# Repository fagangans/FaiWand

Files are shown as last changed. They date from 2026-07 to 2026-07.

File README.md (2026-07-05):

# AI Magic Wand (ESP32 + MPU6050 + OLED + Mic + Speaker)

Proyek "AI Magic Wand" terinspirasi dari [TensorFlow Lite Magic Wand Codelab](https://codelabs.developers.google.com/codelabs/ai-magicwand)
Google, tapi dibangun dengan hardware yang jauh lebih murah dan gampang didapat:
**ESP32 DevKit V1 + MPU6050 + OLED SSD1306 0.96" + mikrofon I2S (INMP441) + speaker
I2S (MAX98357A)**, terintegrasi dengan **AI lokal (speech-to-speech dua arah)** milik
kamu sendiri di jaringan LAN — bukan cloud API.

Kamu bisa **bicara ke tongkat** (push-to-talk, tahan tombol BOOT) dan AI menjawab lewat
suara + teks di tongkat, ATAU **menggerakkan tongkat** (gesture) untuk trigger respons
tetap yang lebih ringkas.

## Struktur repo

```
firmware/magic_wand/     -> Sketch Arduino (buka magic_wand.ino di Arduino IDE)
server/                   -> Server AI lokal Node.js (gesture/suara -> teks + audio TTS)
docs/BOM.md               -> Daftar komponen + estimasi harga
docs/WIRING.md             -> Panduan wiring lengkap + setup jaringan AI lokal
docs/EDGE_IMPULSE_GUIDE.md -> Cara training model gesture custom
docs/ENCLOSURE.md          -> Saran casing/enclosure tongkat
enclosure/                 -> Model 3D gagang (.scad + .stl siap print)
```

## Arsitektur singkat

```
                     ┌── GESTURE (Lumos/Wave/Circle) ──┐   ┌── PUSH-TO-TALK (tombol BOOT) ──┐
                     |  MPU6050 -> ESP32 klasifikasi    |   |  Mikrofon I2S rekam ke RAM      |
                     v                                  v   v
                              WiFi (LAN) --> Server AI lokal kamu
                                        |
                    (gesture: prompt tetap per gesture)
                    (suara: transkrip Whisper lokal -> jadi prompt)
                                        |
                         ┌──────────────┴──────────────┐
                         v                              v
                  Teks respons AI                Audio TTS (mp3)
                  (JSON, untuk OLED)         (di-stream via HTTP ke ESP32)
                         |                              |
                         v                              v
                  Tampil di OLED          Dimainkan lewat speaker I2S
                                          di tongkat (MAX98357A + speaker)
```

**Kenapa klasifikasi gesture tetap on-device (bukan kirim raw sensor ke AI)?** Time-series
classification real-time tidak cocok dikirim sebagai data mentah — lambat dan boros
baterai/bandwidth. Jadi gesture diklasifikasi lokal di ESP32 (model kecil via Edge Impulse,
atau fallback threshold sederhana), baru **hasil klasifikasinya** yang dikirim ke server.

**Kenapa suara (TTS & STT) diproses di server tapi didengar/direkam di tongkat?** ESP32
tidak mampu generate suara atau transkrip suara sendiri — terlalu berat untuk board sekecil
ini. Server (komputer kamu) yang punya daya proses untuk itu:
- **Bicara ke tongkat**: ESP32 rekam suara ke RAM → kirim WAV ke server → server transkrip
  (Whisper lokal, offline) → AI jawab sesuai isi omongan → jawaban (teks+audio) dikirim balik.
- **Tongkat menjawab**: server generate teks + audio TTS → ESP32 **streaming** audio itu dan
  memutarnya langsung lewat speaker I2S di tongkat.

Hasilnya speech-to-speech terasa benar-benar terjadi di tongkat, walau otak pemrosesannya
ada di server lokal kamu.

## Quick start

1. **Hardware**: ikuti `docs/BOM.md` dan `docs/WIRING.md` untuk rakit board (OLED, speaker
   I2S, DAN mikrofon I2S).
2. **Software firmware**:
   - Install Arduino IDE + board support "esp32" (via Boards Manager, cari "esp32" by Espressif).
   - Install library lewat Library Manager: `Adafruit MPU6050`, `Adafruit Unified Sensor`,
     `Adafruit SSD1306`, `Adafruit GFX Library`, `ArduinoJson`, `ESP32-audioI2S` (by schreibfaul1).
     (Mikrofon pakai driver I2S bawaan Arduino-ESP32 core, tidak perlu library tambahan.)
   - Buka folder `firmware/magic_wand/` di Arduino IDE (buka file `magic_wand.ino`).
   - Copy `secrets.h.example` jadi `secrets.h`, isi WiFi SSID/password dan `LOCAL_AI_HOST`
     (hostname mDNS atau IP server AI lokal kamu).
   - Pilih board **"ESP32 Dev Module"** di Tools > Board, pilih port yang sesuai, lalu Upload.
3. **Server AI lokal**: implementasi siap pakai ada di `server/` (Node.js, tanpa API key untuk
   chat AI — pakai AI4Chat + TTS Edge Neural Voice + STT Whisper lokal). Jalankan:
   ```
   cd server && npm install && npm start
   ```
   Lihat `server/README.md` untuk detail kontrak API (`/gesture`, `/voice`, `/audio/:file`).
4. **Test awal (tanpa training model dulu)**: firmware default pakai fallback threshold
   sederhana untuk gesture (`USE_EDGE_IMPULSE_MODEL 0` di `gesture_classifier.h`) — cukup
   untuk memverifikasi wiring, LED, OLED, speaker, mikrofon, dan koneksi ke server AI lokal
   sebelum kamu invest waktu training model gesture asli.
5. **Training model gesture asli**: ikuti `docs/EDGE_IMPULSE_GUIDE.md` step-by-step.
6. **Casing**: file 3D print siap pakai ada di `enclosure/` (STL + sumber `.scad`, sudah
   termasuk lubang mikrofon), atau lihat opsi lain di `docs/ENCLOSURE.md`.

## Cara pakai

| Metode | Aksi |
|---|---|
| **Push-to-talk** | Tahan tombol BOOT, bicara, lepas untuk kirim. AI jawab SESUAI ISI OMONGAN kamu. |
| Gesture `Lumos` | LED menyala kuning terang, tahan ~1.2 detik; nama gesture tampil di OLED |
| Gesture `Wave` | LED kedip biru 4x, kirim ke server AI (prompt TETAP "sapa pengguna..."), tampil + suarakan respons |
| Gesture `Circle` | LED efek sweep ungu-pink; nama gesture tampil di OLED |

Gesture, warna, prompt tetap tiap gesture, dan mana yang trigger AI semuanya bisa diubah di
`firmware/magic_wand/led_effects.cpp`, `firmware/magic_wand/magic_wand.ino`, dan
`server/gesture_server.js` (`GESTURE_PROMPTS`).

## Power management

- Board masuk **deep sleep** otomatis setelah idle (default 30 detik, ubah `IDLE_TIMEOUT_MS`
  di `config.h`).
- Bangun otomatis lewat **interrupt motion-detection MPU6050** (pin `PIN_MPU_INT`) — begitu
  tongkat digerakkan, ESP32 langsung reset & siap deteksi gesture lagi.
- WiFi hanya dinyalakan saat mengirim gesture/suara ke AI lokal dan selama audio streaming
  berlangsung, lalu dimatikan lagi — sehingga hemat baterai saat idle/deep sleep.
- **Catatan baterai**: speaker + amplifier + mikrofon menambah konsumsi arus saat aktif
  (~500mA-1A tergantung volume) — kalau baterai kamu kecil (300-400mAh), daya tahan akan
  berkurang lebih banyak dibanding versi tanpa audio, terutama kalau sering dipakai bicara.

## Catatan penting

- **Jangan commit `secrets.h`** ke git (sudah otomatis di-ignore lewat `.gitignore`) — file itu
  berisi WiFi password dan alamat server AI lokal.
- Perhatikan catatan power supply di `docs/WIRING.md` soal regulator ESP32 vs tegangan LiPo
  3.7V — banyak board versi murah butuh boost converter tambahan biar stabil.
- Server AI lokal dan ESP32 **harus di WiFi/LAN yang sama**. Kalau pakai hostname mDNS
  (`xxx.local`), pastikan OS server mendukung mDNS (lihat `docs/WIRING.md`).
- MAX98357A disambung ke **VIN**, bukan 3V3 (butuh daya lebih untuk menggerakkan speaker) —
  lihat `docs/WIRING.md` untuk detail wiring.
- Model Whisper (speech-to-text) di-download otomatis ~150MB saat pertama kali server
  menerima request `/voice` — butuh internet saat itu saja, setelahnya transkripsi jalan
  offline sepenuhnya.

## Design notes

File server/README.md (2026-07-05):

# FaiWand Gesture AI Server

Server AI lokal untuk AI Magic Wand — menerima **gesture ATAU rekaman suara (push-to-talk)**
dari ESP32, transkrip suara pakai Whisper lokal (kalau lewat suara), membalas teks singkat
untuk OLED, dan generate audio TTS yang di-**stream** ke ESP32 lewat HTTP untuk dimainkan
langsung di speaker tongkat (speech-to-speech dua arah, semua terjadi di tongkat). Tidak
butuh API key untuk chat AI-nya (pakai AI4Chat, dengan fallback PublicAI).

Diadaptasi dari `Ai4Chat.js` + `whisper-server.js` di repo Faganlenwy, disesuaikan dengan
kontrak API yang sudah diasumsikan firmware ESP32 (`ai_client.cpp` + `config.h`).

## Kontrak API

```
POST /gesture
Body:  {"gesture": "Wave"}
Balas: {"text": "Halo! Selamat datang...", "audio_url": "/audio/gesture-171234.mp3"}
```

```
POST /voice                       (push-to-talk: kamu bicara, AI jawab sesuai isi omongan)
Body:  raw bytes WAV 16kHz/16-bit mono (Content-Type: audio/wav)
Balas: {"text": "...", "audio_url": "/audio/gesture-171234.mp3"}
```

```
GET /audio/:filename
Balas: file mp3 (di-stream ESP32 lewat library ESP32-audioI2S)
```

```
GET /health
Balas: {"status": "ok", ...}
```

## Jalankan

```
cd server
npm install
cp .env.example .env   # opsional, default port 5000
npm start
```

Server berjalan di `http://localhost:5000` (atau IP LAN mesin ini). Set `LOCAL_AI_HOST` di
`firmware/magic_wand/secrets.h` ke hostname/IP mesin ini, dan pastikan ESP32 + server ada di
WiFi/LAN yang sama.

**Catatan `npm install` pertama kali**: dependency `@xenova/transformers` (untuk speech-to-text
Whisper lokal) cukup besar, dan pertama kali `/voice` dipanggil, model Whisper-tiny akan
di-download otomatis (~150MB, sekali saja, di-cache lokal) — butuh koneksi internet saat itu,
tapi **setelahnya semua transkripsi jalan offline**, tidak ada audio yang dikirim ke cloud.

## Menambah/mengubah gesture

Edit `GESTURE_PROMPTS` di `gesture_server.js` — tiap gesture punya satu prompt tetap yang
dikirim ke AI. Gesture yang tidak terdaftar memakai `DEFAULT_PROMPT`. Ini hanya berlaku untuk
jalur `/gesture` — jalur `/voice` selalu pakai isi transkrip suara kamu sebagai prompt.

## Alur audio: kenapa file mp3, bukan diputar langsung di server?

1. Server dapat teks (dari AI4Chat/PublicAI, berdasarkan gesture ATAU transkrip suara), lalu
   generate audio TTS-nya (Edge Neural Voice), simpan sebagai file mp3 sementara di
   `server/public/audio/`.
2. Server balas ke ESP32: `{"text": ..., "audio_url": "/audio/xxx.mp3"}`.
3. ESP32 menampilkan teks di OLED **segera**, lalu **streaming** file audio itu langsung dari
   URL tersebut dan memutarnya lewat speaker I2S yang terpasang di tongkat.
4. File mp3 di server otomatis dihapus ~60 detik kemudian (cukup waktu untuk ESP32 selesai
   streaming), supaya folder `public/audio/` tidak menumpuk file lama.

Kalau kamu mau ubah durasi cleanup, ubah angka `60_000` (ms) di `textToSpeechFile()` pada
`gesture_server.js`.

## Troubleshooting

- **`npm install` gagal di paket `sharp`**: `sharp` adalah dependency dari `@xenova/transformers`
  (dipakai untuk model vision, tidak kita pakai untuk audio, tapi tetap ter-install). Kalau
  gagal karena masalah jaringan/firewall saat download binary, coba ulangi `npm install` di
  jaringan yang tidak dibatasi proxy/firewall ketat. Ini masalah environment, bukan bug di kode.
- **AI4Chat & PublicAI dua-duanya gagal**: endpoint publik ini kadang rate-limit/down —
  server akan balas HTTP 502 ke ESP32. Cek log server untuk detail error.
- **ESP32 tidak bisa connect**: pastikan port `GESTURE_PORT` (default 5000) sama dengan
  `LOCAL_AI_PORT` di `config.h`, dan firewall OS server tidak memblokir port tersebut di LAN.
- **Suara tidak keluar di tongkat**: cek Serial Monitor ESP32 — kalau log `[Audio] Gagal mulai
  streaming`, kemungkinan `audio_url` tidak terjangkau dari ESP32 (beda jaringan, firewall,
  atau port server tertutup). Test manual dulu buka URL `audio_url` itu di browser dari device
  lain yang satu jaringan dengan ESP32.
- **Audio putus-putus/berisik**: biasanya karena WiFi lemah (sinyal jauh dari router) atau
  server terlalu sibuk generate TTS bersamaan dengan request lain. Pastikan ESP32 dekat
  dengan router/AP saat testing.
- **Transkrip suara ngaco/kosong**: model `whisper-tiny` itu model paling kecil/cepat, akurasi
  lumayan tapi tidak sempurna terutama untuk Bahasa Indonesia dengan aksen tertentu atau
  lingkungan berisik. Kalau butuh lebih akurat (tapi lebih lambat & lebih berat di CPU), ganti
  `Xenova/whisper-tiny` di `speech_to_text.js` jadi `Xenova/whisper-base` atau `Xenova/whisper-small`.

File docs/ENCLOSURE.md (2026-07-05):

# Saran Casing / Enclosure

## Opsi 1 — Pipa PVC/akrilik (paling murah, tanpa 3D printer)
- Pipa PVC diameter ~20-25mm, panjang 25-30cm sebagai "badan tongkat".
- ESP32 + MPU6050 + baterai ditempatkan di bagian pegangan (lebih tebal/lebar untuk muat komponen).
- LED RGB dipasang di ujung, dengan **diffuser** dari bola pingpong dipotong setengah atau
  potongan tabung akrilik susu (frosted) supaya cahaya menyebar rata, bukan titik terang tajam.
- Tutup ujung pegangan pakai dop PVC yang dibor untuk switch ON/OFF dan port USB (akses charging
  tanpa bongkar casing).

## Opsi 2 — 3D print (kalau ada akses printer)
- Desain 2 bagian: **grip** (menampung ESP32, baterai, TP4056, switch) dan **shaft** (menyalurkan
  kabel LED ke ujung).
- Material: PETG lebih baik dari PLA untuk ketahanan (PLA getas kalau dipakai gesture cepat/wave).
- Sisakan slot akses untuk port USB-C/micro-USB charging tanpa bongkar total.
- Cari template dasar "wand enclosure" atau "pen case" di Thingiverse/Printables sebagai starting
  point, lalu sesuaikan dimensi internal ke ukuran board ESP32 DevKit V1 (~52x28mm) + baterai LiPo.

## Opsi 3 — Tongkat kayu/akrilik bekas (paling cepat, prototyping)
- Pakai tongkat kayu bulat (dowel) yang dilubangi tengahnya, atau tongkat harry-potter-style yang
  dijual online sebagai basis, lalu tempel komponen di bagian pegangan pakai hot glue/velcro.
- Cocok untuk iterasi cepat sebelum commit ke desain casing permanen.

## Pertimbangan umum semua opsi
- **Sirkulasi kabel**: MPU6050 idealnya ditempatkan sedekat mungkin ke ujung gerak (tip) supaya
  sensitivitas gesture lebih baik, tapi ini menambah panjang kabel dari grip. Kompromi umum: taruh
  MPU6050 di grip juga (dekat tangan) karena gesture berbasis rotasi/pergerakan tangan tetap
  terbaca dengan baik dari situ, dan ini menyederhanakan wiring.
- **Ventilasi/panas**: ESP32 + WiFi aktif bisa hangat saat request AI API; casing tertutup rapat
  tanpa 3D print (misal PVC solid) sebaiknya punya sedikit celah ventilasi.
- **Akses charging**: selalu sisakan akses ke port USB TP4056 tanpa perlu bongkar casing.
- **Berat & keseimbangan**: taruh baterai (komponen terberat) sedekat mungkin ke tangan (grip) demi
  keseimbangan tongkat saat dipakai gesture cepat.

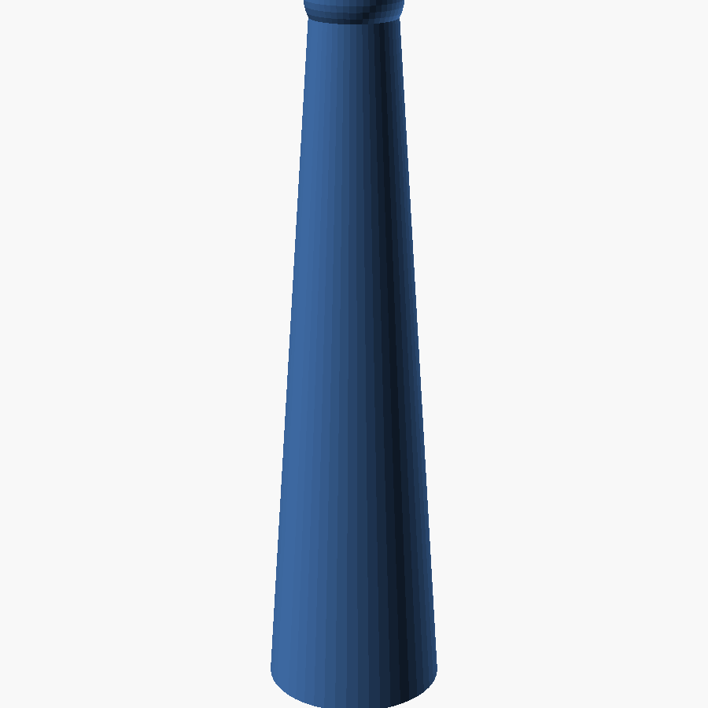
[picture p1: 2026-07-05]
enclosure/preview_shaft.png

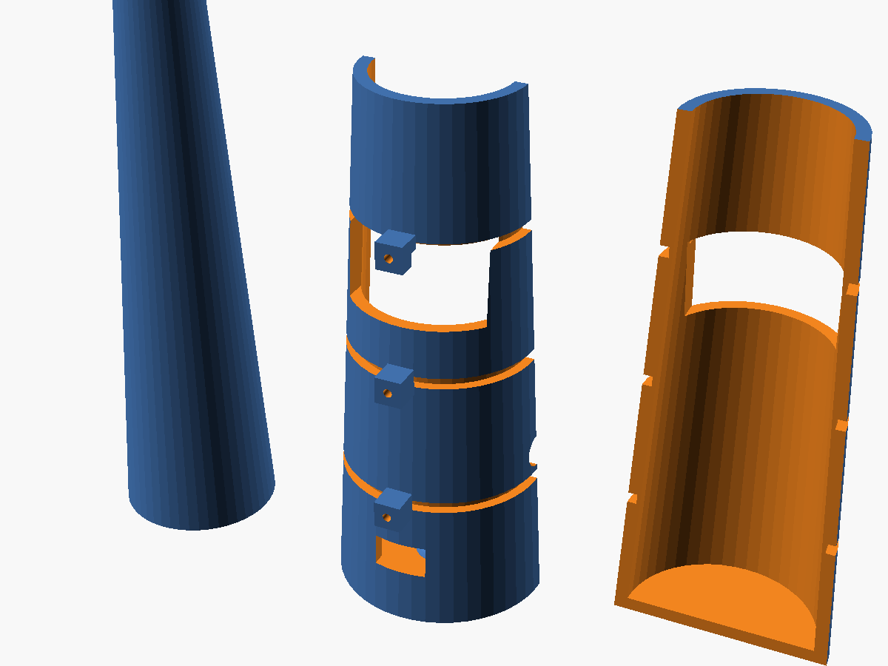
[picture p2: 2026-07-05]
enclosure/preview.png

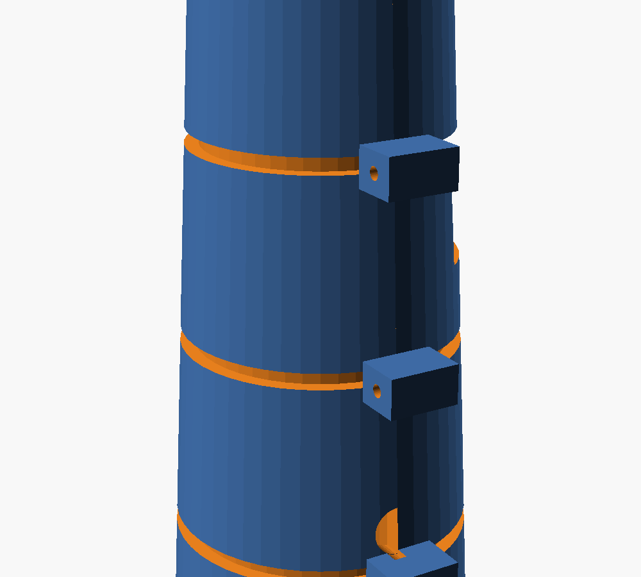
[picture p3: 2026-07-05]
enclosure/preview_final_oled.png

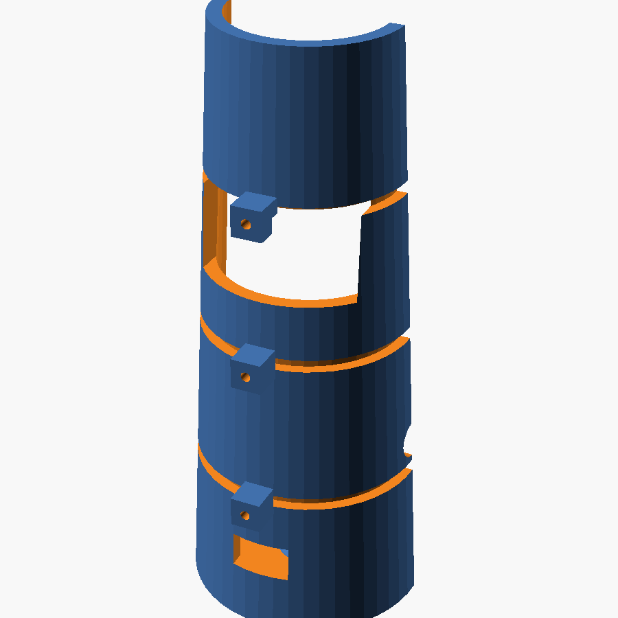
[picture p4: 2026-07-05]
enclosure/preview_bottom.png

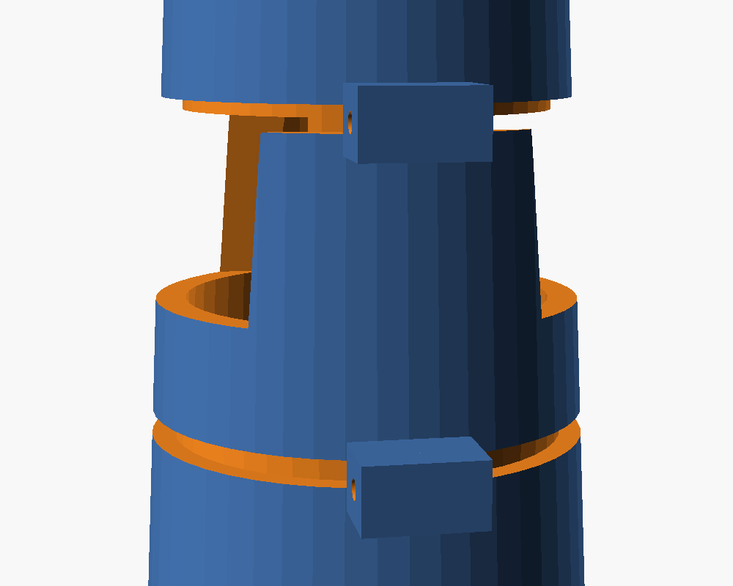
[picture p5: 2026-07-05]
enclosure/preview_seam_countersink.png

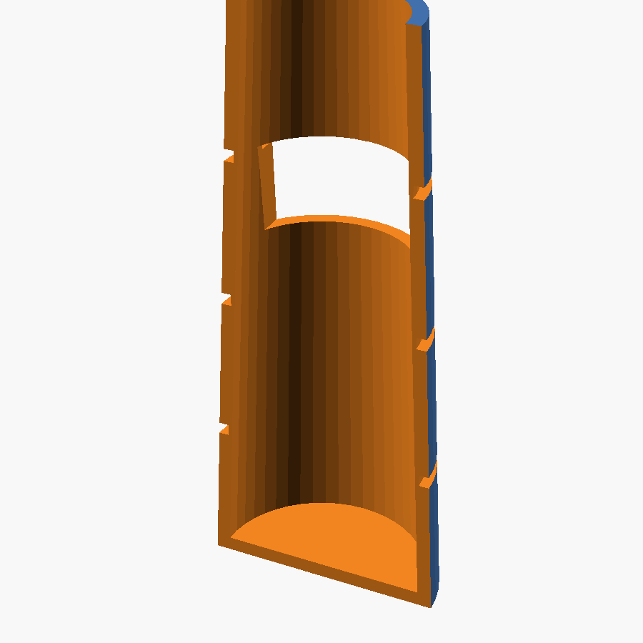
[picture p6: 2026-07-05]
enclosure/preview_top.png

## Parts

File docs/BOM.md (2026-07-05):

# Bill of Materials — AI Magic Wand

| # | Komponen | Spesifikasi | Perkiraan Harga (IDR) | Catatan |
|---|---|---|---|---|
| 1 | ESP32 DevKit V1 | 30-pin, chip CP2102/CH340 | 45.000 – 65.000 | Beli yang sudah ada breakout header, mudah cari di marketplace lokal |
| 2 | MPU6050 module | Breakout GY-521 | 8.000 – 15.000 | Sudah include regulator 3.3V & pull-up I2C |
| 3 | LED RGB common-anode/cathode | 5mm atau modul WS2812 (opsional upgrade) | 2.000 – 5.000 | Kalau pakai WS2812, hanya butuh 1 pin data, tapi kode perlu diubah (lihat catatan di bawah) |
| 4 | Resistor 220Ω x3 | Untuk tiap kaki LED (kalau bukan modul) | 1.000 | Skip jika pakai modul RGB dengan resistor bawaan |
| 5 | Baterai LiPo 3.7V | 500–1000mAh, konektor JST-PH 2 pin | 25.000 – 45.000 | Sesuaikan ukuran dengan casing tongkat |
| 6 | Modul charger TP4056 | Dengan proteksi (versi ada chip DW01+FS8205) | 3.000 – 6.000 | WAJIB pilih versi dengan proteksi over-discharge/short-circuit |
| 7 | Switch ON/OFF slide/tactile | Mini slide switch | 1.000 – 3.000 | Pasang antara baterai dan ESP32/TP4056 output |
| 8 | Push button (opsional) | Tactile 6x6mm | 500 | Untuk trigger manual/mode training, bisa juga pakai tombol BOOT bawaan ESP32 |
| 9 | Kabel jumper female-female & male-female | Secukupnya | 5.000 | Untuk wiring prototipe di breadboard |
| 10 | Breadboard mini (opsional, untuk prototyping) | 400/800 titik | 8.000 – 15.000 | Bisa dilepas setelah pindah ke solder permanen |
| 11 | Casing/tongkat | Lihat docs/ENCLOSURE.md | Variatif | PVC pipe, 3D print, atau tongkat kayu bekas |
| 12 | OLED SSD1306 0.96" I2C | 128x64, alamat default 0x3C | 15.000 – 25.000 | Dipakai untuk tampilkan nama gesture & respons teks dari AI lokal |
| 13 | Amplifier I2S MAX98357A | Modul mono class-D, ~3W | 12.000 – 20.000 | Untuk memutar suara AI (TTS) yang di-streaming dari server, langsung di tongkat |
| 14 | Speaker mini | 4Ω atau 8Ω, 2-3W, diameter ~20-28mm | 8.000 – 20.000 | Sesuaikan diameter dengan ruang yang tersedia di enclosure |
| 15 | Mikrofon I2S INMP441 | Modul digital I2S | 15.000 – 25.000 | Untuk push-to-talk (bicara ke tongkat), lihat `docs/WIRING.md` |

**Total estimasi (dengan OLED + speaker + mikrofon, tanpa casing 3D print):** sekitar **Rp 150.000 – 250.000**

> Catatan: tombol **push-to-talk** memakai tombol **BOOT bawaan** ESP32 (item #8 di atas jadi
> opsional/tidak wajib beli baru) — tahan tombol sambil bicara, lepas untuk kirim ke AI.

## Catatan Pemilihan Komponen

- **ESP32 DevKit V1** dipilih karena: dual-core, WiFi built-in, cukup RAM/flash untuk model TFLite Micro kecil hasil Edge Impulse, dan harga jauh lebih murah dari Arduino Nano 33 BLE Sense (board asli di Google Codelab).
- **MPU6050** adalah alternatif termurah dari sensor IMU yang dipakai Google (yang aslinya pakai sensor built-in Arduino Nano 33 BLE Sense). Akurasi cukup untuk gesture classification.
- Kalau nanti mau upgrade ke **WS2812 (NeoPixel)** hanya butuh 1 GPIO data + resistor 300-500Ω di jalur data + kapasitor 100-1000uF di power — tapi kode `led_effects.cpp` perlu diganti untuk pakai library `Adafruit_NeoPixel` alih-alih `analogWrite`.
- **TP4056 dengan proteksi** itu wajib, bukan opsional — versi tanpa proteksi bisa merusak baterai LiPo kalau over-discharge.
- **MAX98357A** dipilih karena paling murah & gampang diintegrasikan (I2S langsung dari ESP32, tanpa DAC eksternal terpisah). Suara AI (hasil TTS server) di-streaming lewat WiFi dan dimainkan langsung di tongkat, bukan di komputer server — lihat `docs/WIRING.md` untuk pin I2S.
- **INMP441** dipilih karena digital I2S (bukan analog), jadi tidak perlu ADC eksternal dan minim noise dibanding mic analog/electret biasa. Rekaman suara kamu (push-to-talk) di-kirim ke server untuk speech-to-text, BUKAN diproses di ESP32 — ESP32 cuma merekam ke buffer RAM lalu kirim.

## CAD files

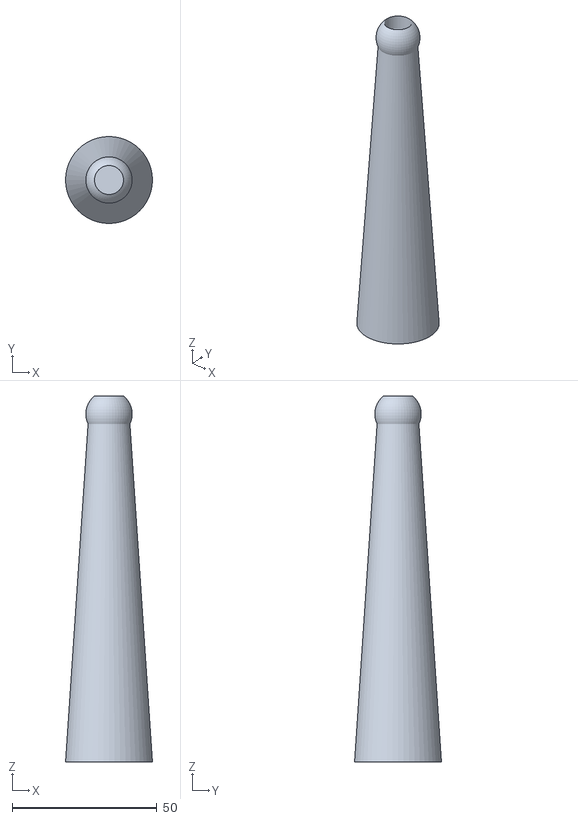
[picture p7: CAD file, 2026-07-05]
enclosure/magic_wand_shaft.stl
30.0 x 30.0 x 126.2

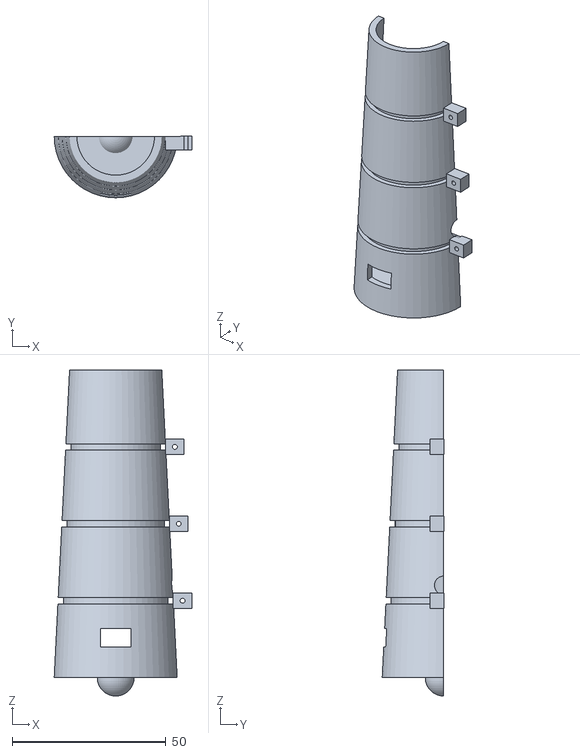
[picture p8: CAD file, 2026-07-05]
enclosure/magic_wand_grip_bottom.stl
44.8 x 20.0 x 106.0

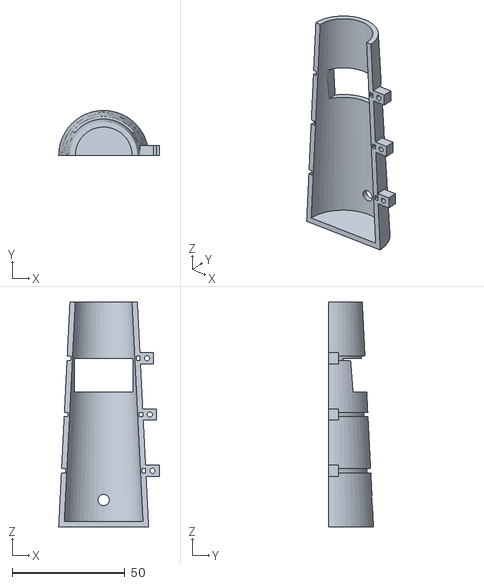
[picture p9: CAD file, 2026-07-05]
enclosure/magic_wand_grip_top.stl
44.8 x 20.0 x 100.0

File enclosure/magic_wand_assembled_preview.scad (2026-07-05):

// ============================================================
// AI Magic Wand — Gagang v9 FINAL (+ lubang mikrofon push-to-talk)
// STYLE = 0 -> Polos | 1 -> Elegan | 2 -> Kristal
//
// Riwayat: v6 cincin dipotong sebelum flange; v7 flange dipindah ke garis
// sambungan yang benar; v8 tambah countersink + jendela OLED cuma 1 sisi;
// v9 tambah lubang akustik mikrofon (INMP441, push-to-talk) di grip_top,
// di posisi terpisah dari jendela OLED & tab baut supaya tidak bentrok.
//
// BAUT: sekrup mainan/RC self-tapping ~2mm x 6-8mm, dijual di toko mainan
// RC/elektronik/sparepart remote — tidak perlu mur.
// ============================================================

STYLE = 1;

grip_length      = 100;
wall_thickness   = 2.5;

usb_cutout_w     = 10;
usb_cutout_h     = 6;
usb_cutout_z     = 10;

switch_hole_d    = 6;
switch_z         = 30;

oled_window_w    = 26;
oled_window_h    = 15;
oled_window_z    = grip_length - 40;

mic_hole_d       = 5;   // lubang akustik ke mikrofon INMP441 (mic dipasang di dalam, dekat lubang ini)
mic_hole_z       = 12;  // posisi -- sengaja jauh dari ring/screw (25/50/75) & jendela OLED (52.5-67.5)

grip_d_back      = 40;
grip_d_front     = 30;
ring_count       = 3;
ring_width       = 2;
ring_depth       = 0.8;
crystal_sides    = 6;

shaft_length     = 120;
shaft_d          = 14;
led_tip_d        = 10;

flange_out        = 6;   // seberapa jauh flange menjorok keluar dari permukaan (arah X)
flange_deep       = 4;   // panjang flange di tiap sisi sambungan (Y)
tab_h             = 5;   // tinggi flange (Z)
screw_hole_clear  = 2.3;
countersink_d     = 4.2;  // diameter corong tempat kepala sekrup duduk rata
countersink_depth = 1.6;  // kedalaman corong (sesuaikan dgn tinggi kepala sekrup kamu)
screw_hole_pilot  = 1.6;

screw_z_positions = (STYLE == 1)
    ? [for (i = [1:ring_count]) grip_length * i / (ring_count + 1)]
    : [15, 50, 85];

$fn = 48;

function outer_r(z) = (grip_d_back/2) + (grip_d_front/2 - grip_d_back/2) * (z / grip_length);

module tapered_body(d_back, d_front, len) {
    if (STYLE == 2) {
        linear_extrude(height = len, scale = d_front/d_back, $fn = crystal_sides)
            circle(d = d_back, $fn = crystal_sides);
    } else {
        cylinder(h = len, r1 = d_back/2, r2 = d_front/2);
    }
}

module tapered_cavity(d_back, d_front, len) {
    if (STYLE == 2) {
        linear_extrude(height = len, scale = (d_front - 2*wall_thickness)/(d_back - 2*wall_thickness), $fn = crystal_sides)
            circle(d = d_back - 2*wall_thickness, $fn = crystal_sides);
    } else {
        cylinder(h = len, r1 = d_back/2 - wall_thickness, r2 = d_front/2 - wall_thickness);
    }
}

module decorative_rings() {
    if (STYLE == 1) {
        for (i = [1 : ring_count]) {
            z_pos = grip_length * i / (ring_count + 1);
            r_here = outer_r(z_pos);
            translate([0, 0, z_pos])
                rotate_extrude($fn = $fn)
                    translate([r_here - ring_depth, 0, 0])
                        square([ring_depth + 1, ring_width], center = true);
        }
    }
}

module back_cap() {
    if (STYLE == 1) sphere(r = grip_d_back/2 * 0.3);
}

module flange_bottom(z_pos) {
    r_here = outer_r(z_pos);
    translate([r_here - 0.05, -(flange_deep + 0.5), z_pos - tab_h/2])
        cube([flange_out + 0.05, flange_deep + 0.55, tab_h]);
}

module flange_top(z_pos) {
    r_here = outer_r(z_pos);
    translate([r_here - 0.05, -0.05, z_pos - tab_h/2])
        cube([flange_out + 0.05, flange_deep + 0.55, tab_h]);
}

module screw_hole_bottom(z_pos) {
    r_here = outer_r(z_pos);
    translate([r_here + flange_out/2, -(flange_deep + 1.5), z_pos])
        rotate([-90, 0, 0])
            cylinder(h = flange_deep + 2.5, d = screw_hole_pilot);
}

module screw_hole_top(z_pos) {
    r_here = outer_r(z_pos);
    // lubang tembus utama (clearance, sekrup lewat bebas)
    translate([r_here + flange_out/2, -1, z_pos])
        rotate([-90, 0, 0])
            cylinder(h = flange_deep + 2, d = screw_hole_clear);
    // countersink: corong kecil di ujung luar flange, biar kepala sekrup rata/tersembunyi
    translate([r_here + flange_out/2, flange_deep + 0.5, z_pos])
        rotate([-90, 0, 0])
            cylinder(h = countersink_depth, d1 = countersink_d, d2 = screw_hole_clear);
}

module ringed_hollow_body() {
    difference() {
        tapered_body(grip_d_back, grip_d_front, grip_length);
        translate([0, 0, wall_thickness])
            tapered_cavity(grip_d_back, grip_d_front, grip_length);
        decorative_rings();
    }
}

module grip_bottom() {
    difference() {
        union() {
            ringed_hollow_body();
            back_cap();
            for (z_pos = screw_z_positions) flange_bottom(z_pos); // tab ditambah TERAKHIR, solid, tidak kepotong cincin
        }

        translate([-grip_d_back/2 - 1, 0, -grip_d_back/2])
            cube([grip_d_back + 2, grip_d_back + 2, grip_length + grip_d_back]);

        translate([-usb_cutout_w/2, -outer_r(usb_cutout_z) - 1, usb_cutout_z])
            cube([usb_cutout_w, outer_r(usb_cutout_z) + 2, usb_cutout_h]);

        translate([outer_r(switch_z) - wall_thickness - 2, 0, switch_z])
            rotate([0, 90, 0])
                cylinder(h = wall_thickness + 4, d = switch_hole_d);

        // Jendela OLED SENGAJA TIDAK dipotong di sini — layar OLED cuma
        // menghadap 1 arah (dipasang menghadap ke grip_top), jendela cukup
        // di satu shell saja (lihat grip_top() di bawah). Memotong di kedua
        // shell cuma bikin lubang sia-sia di sisi belakang modul yang tidak
        // ada tampilan apapun, dan melemahkan casing tanpa manfaat.

        for (z_pos = screw_z_positions) screw_hole_bottom(z_pos); // lubang baut dibor terakhir, tembus tab yang sudah solid
    }
}

module grip_top() {
    difference() {
        union() {
            ringed_hollow_body();
            for (z_pos = screw_z_positions) flange_top(z_pos);
        }

        translate([-grip_d_back/2 - 1, -grip_d_back - 2, -1])
            cube([grip_d_back + 2, grip_d_back + 2, grip_length + 2]);

        translate([-oled_window_w/2, 0, oled_window_z])
            cube([oled_window_w, outer_r(oled_window_z) + 2, oled_window_h]);

        // Lubang akustik mikrofon -- di sisi yang sama dengan OLED (front),
        // posisi z terpisah supaya tidak tumpang tindih dengan jendela OLED/ring/screw.
        translate([0, 0, mic_hole_z])
            rotate([-90, 0, 0])
                cylinder(h = outer_r(mic_hole_z) + 2, d = mic_hole_d);

        for (z_pos = screw_z_positions) screw_hole_top(z_pos);
    }
}

module wand_shaft() {
    difference() {
        if (STYLE == 2) {
            linear_extrude(height = shaft_length, scale = shaft_d/grip_d_front, $fn = crystal_sides)
                circle(d = grip_d_front, $fn = crystal_sides);
        } else {
            cylinder(h = shaft_length, r1 = grip_d_front/2, r2 = shaft_d/2);
        }
        translate([0, 0, -1])
            cylinder(h = shaft_length + 2, d = 4);
    }
    translate([0, 0, shaft_length])
        difference() {
            if (STYLE == 1) {
                sphere(r = shaft_d/2 + 1);
            } else {
                cylinder(h = 8, r1 = shaft_d/2, r2 = shaft_d/2 * 0.6, $fn = (STYLE == 2 ? crystal_sides : $fn));
            }
            translate([0, 0, 1]) cylinder(h = shaft_d, d = led_tip_d);
        }
}


union() {
    grip_bottom();
    grip_top();
}
translate([0, 0, grip_length])
    wand_shaft();

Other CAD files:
enclosure/magic_wand_handle.scad

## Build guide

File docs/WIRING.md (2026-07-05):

# Wiring Diagram — AI Magic Wand (ESP32 DevKit V1)

## Diagram teks (skematik sederhana)

```
                          ESP32 DevKit V1
                       ┌───────────────────┐
        MPU6050 SCL ───┤ GPIO22 (SCL)      │
        MPU6050 SDA ───┤ GPIO21 (SDA)      │
        MPU6050 INT ───┤ GPIO27            │  (wake-on-motion, deep sleep)
        MPU6050 VCC ───┤ 3V3               │
        MPU6050 GND ───┤ GND               │
                       │                   │
        OLED   SCL  ───┤ GPIO22 (SCL, bus sama dgn MPU6050) │
        OLED   SDA  ───┤ GPIO21 (SDA, bus sama dgn MPU6050) │
        OLED   VCC  ───┤ 3V3               │
        OLED   GND  ───┤ GND               │
                       │                   │
        LED  R      ───┤ GPIO25 ──[220Ω]── │──> kaki R LED RGB
        LED  G      ───┤ GPIO26 ──[220Ω]── │──> kaki G LED RGB
        LED  B      ───┤ GPIO33 ──[220Ω]── │──> kaki B LED RGB
        LED  GND/COM ──┤ GND (common cathode) atau 3V3 (common anode, lihat catatan)
                       │                   │
        Tombol BOOT ───┤ GPIO0 (bawaan board, tidak perlu wiring tambahan)
                       │                   │
        MAX98357A BCLK ┤ GPIO14            │
        MAX98357A LRC  ┤ GPIO32            │
        MAX98357A DIN  ┤ GPIO13            │
        MAX98357A VIN  ┤ VIN (bukan 3V3 -- amp butuh daya lebih untuk speaker) │
        MAX98357A GND  ┤ GND               │
        MAX98357A GAIN ┤ (lihat catatan di bawah)                              │
                       │                   │
        INMP441 SCK  ──┤ GPIO4             │  (I2S clock mikrofon)
        INMP441 WS   ──┤ GPIO5             │  (I2S word select mikrofon)
        INMP441 SD   ──┤ GPIO18            │  (I2S data IN dari mic ke ESP32)
        INMP441 VDD  ──┤ 3V3               │
        INMP441 GND  ──┤ GND               │
        INMP441 L/R  ──┤ GND (pilih channel kiri)                              │
                       │                   │
        Baterai LiPo ──┤ VIN / 5V (via TP4056 OUT+) │
                       │ GND (via TP4056 OUT-)       │
                       └───────────────────┘

        Baterai LiPo (JST) ──> TP4056 B+/B-
        TP4056 OUT+/OUT- ──> Switch ON/OFF ──> ESP32 VIN & GND
```

## Detail koneksi

### MPU6050 (I2C)
| MPU6050 Pin | ESP32 Pin | Keterangan |
|---|---|---|
| VCC | 3V3 | Jangan pakai 5V walau modul GY-521 punya regulator, demi konsistensi logic level I2C |
| GND | GND | |
| SCL | GPIO22 | Default I2C clock ESP32 |
| SDA | GPIO21 | Default I2C data ESP32 |
| INT | GPIO27 | Untuk wake-on-motion dari deep sleep |
| AD0 | GND (atau biarkan floating) | Set alamat I2C ke 0x68 (default) |

### OLED SSD1306 0.96" (I2C)
| OLED Pin | ESP32 Pin | Keterangan |
|---|---|---|
| VCC | 3V3 | |
| GND | GND | |
| SCL | GPIO22 | Bus I2C sama dengan MPU6050 — aman karena alamat beda (OLED 0x3C, MPU6050 0x68) |
| SDA | GPIO21 | Bus I2C sama dengan MPU6050 |

Tidak perlu resistor pull-up tambahan — modul GY-521 dan modul OLED umumnya sudah punya
pull-up on-board masing-masing; kalau layar tidak stabil/garis-garis, coba lepas salah satu
pull-up modul (cabut satu resistor 4.7kΩ di salah satu breakout) supaya tidak dobel.

### LED RGB
- Kalau pakai **LED diskrit 4-kaki (common cathode)**: kaki common ke GND, tiap kaki R/G/B ke GPIO lewat resistor 220Ω.
- Kalau **common anode**: kaki common ke 3V3, dan set `LED_ACTIVE_LOW true` di `config.h` supaya logika nyala/mati kebalik dengan benar.
- Kalau pakai **modul RGB siap pakai** (biasanya sudah ada resistor internal), tinggal sambung 3 pin data + GND/VCC sesuai datasheet modul.

### Power (Baterai LiPo + TP4056)
1. Baterai LiPo → konektor B+/B- di TP4056.
2. TP4056 OUT+ dan OUT- → switch ON/OFF → ESP32 pin **VIN** (bukan 3V3!) dan **GND**.
3. Port micro-USB/USB-C di TP4056 dipakai untuk charging — jangan sambung USB ini ke ESP32 secara bersamaan saat charging kalau switch dalam posisi ON (bisa, tapi pastikan arus cukup).
4. ESP32 DevKit V1 punya regulator 5V→3.3V on-board, jadi VIN bisa menerima ~5V dari baterai LiPo yang sudah di-boost, **ATAU** kalau baterai LiPo 3.7V langsung disambung ke VIN, pastikan board kamu punya regulator yang menerima input serendah itu (banyak board DevKit V1 punya AMS1117 yang butuh input >4.5V agar output stabil 3.3V). **Rekomendasi paling aman:** sambungkan baterai LiPo ke pin **3V3** langsung (bypass regulator) HANYA jika board mendukung, atau lebih aman lagi gunakan modul boost converter 3.7V→5V di antara TP4056 dan VIN.

> ⚠️ **Penting soal power**: Banyak DevKit V1 versi murah regulatornya (AMS1117-3.3) butuh minimum ~4.5-5V di VIN untuk output stabil 3.3V. LiPo 3.7V (single cell) yang di-drop ke ~3.0V saat hampir habis bisa membuat ESP32 brownout. Solusi paling aman & murah: tambahkan **modul boost converter kecil (MT3608, ~3.000 IDR)** antara output TP4056 dan VIN ESP32, di-set ke 5V.

### Push-to-talk (tombol BOOT, GPIO0)
Bisa pakai tombol **BOOT** bawaan board (GPIO0) — tidak perlu wiring tambahan. Tahan tombol
sambil bicara ke mikrofon, lepas untuk kirim rekaman ke AI. Dibaca lewat
`digitalRead(PIN_BUTTON)` (active LOW, pakai `INPUT_PULLUP`).

### Speaker (I2S, MAX98357A + speaker mini)
| MAX98357A Pin | ESP32 Pin | Keterangan |
|---|---|---|
| VIN | VIN (bukan 3V3) | Amplifier butuh daya lebih besar untuk menggerakkan speaker; 3V3 regulator ESP32 tidak cukup kuat |
| GND | GND | |
| BCLK | GPIO14 | I2S bit clock |
| LRC | GPIO32 | I2S word select (L/R clock) |
| DIN | GPIO13 | I2S data in (audio digital dari ESP32 ke amp) |
| GAIN | Floating (default) atau ke GND (gain lebih tinggi) — sesuaikan dengan volume speaker yang diinginkan | |
| SD | Floating (aktif) atau ke GND lewat resistor kalau mau kontrol shutdown manual | |
| Speaker + / - | Ke speaker mini 4-8Ω | Polaritas tidak terlalu kritis untuk speaker mono kecil |

> ⚠️ **Penting**: MAX98357A disambung ke **VIN** (bukan 3V3) karena perlu daya lebih untuk
> menggerakkan speaker dengan volume cukup. Pastikan baterai/boost converter (MT3608) yang
> sudah ada mampu suplai arus tambahan ini (~500mA-1A saat volume tinggi) — kalau baterai
> kamu kecil (300-400mAh), daya tahan akan berkurang signifikan saat audio sering diputar.

### Jendela speaker & mikrofon di enclosure
Karena speaker perlu suara bisa keluar dan mikrofon perlu bisa "dengar" suara kamu, enclosure
gagang perlu **lubang-lubang kecil (grille)** di dekat posisi masing-masing dipasang. File
`enclosure/magic_wand_handle.scad` **sudah** menyertakan 1 lubang mikrofon kecil (lihat bagian
`mic_hole_d` di parameter) — untuk speaker, sesuaikan/tambahkan grille manual sesuai posisi
speaker kamu pasang nanti (biasanya di area yang sama dengan grip, dekat mulut pengguna).

## Diagram visual (disarankan)
Untuk diagram visual grafis (bukan teks), gunakan [Wokwi](https://wokwi.com) — sudah ada simulator ESP32 + MPU6050 online, gratis, dan bisa langsung simulasikan sebagian logic (I2C, LED) sebelum wiring fisik. Cari template "ESP32 MPU6050" di Wokwi sebagai starting point lalu sesuaikan pin sesuai tabel di atas.

## Jaringan: ESP32 <-> Server AI Lokal
ESP32 dan server AI lokal (yang menjalankan speech-to-speech/speech-to-text) harus berada di
**WiFi/LAN yang sama**. Tidak ada wiring fisik antara keduanya — komunikasi murni lewat WiFi
(HTTP). Yang perlu disiapkan, server AI lokal harus punya 3 endpoint (sudah diimplementasikan
di `server/gesture_server.js`, tinggal jalankan):
1. `POST /gesture` — body `{"gesture": "Wave"}` → balas `{"text": ..., "audio_url": ...}`
2. `POST /voice` — body raw WAV (push-to-talk) → balas `{"text": ..., "audio_url": ...}`
3. `GET /audio/:file` — file mp3 hasil TTS untuk di-stream ESP32

Isi `LOCAL_AI_HOST` di `secrets.h` dengan hostname mDNS server (`namaserver.local`) atau IP
statis-nya. Kalau pakai hostname mDNS, pastikan OS server AI lokal mendukung mDNS/Bonjour
(bawaan di macOS, perlu paket `avahi-daemon` di Linux, atau software "Bonjour" di Windows).

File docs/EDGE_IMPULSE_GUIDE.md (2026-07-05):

# Training Model Gesture dengan Edge Impulse

Firmware di repo ini default jalan pakai **fallback threshold sederhana** (`USE_EDGE_IMPULSE_MODEL 0`
di `gesture_classifier.h`) supaya kamu bisa test hardware dulu tanpa nunggu training model. Setelah
model Edge Impulse siap, tinggal flip flag itu ke `1`.

## 1. Persiapan akun & project
1. Daftar gratis di https://studio.edgeimpulse.com
2. Buat project baru, pilih tipe **"Accelerometer data"** (walau kita juga pakai gyro, EI tetap
   menghandle multi-axis time-series dengan baik).

## 2. Kumpulkan data training

Cara termudah: **pakai serial output langsung dari ESP32** sebagai data source custom, atau pakai
**Edge Impulse Data Forwarder** (lebih gampang karena mereka yang urus format & upload).

### Opsi A — Edge Impulse Data Forwarder (rekomendasi)
1. Install CLI: `npm install -g edge-impulse-cli`
2. Buat sketch collector sementara (terpisah dari `magic_wand.ino`) yang mencetak sample ke Serial
   dengan format CSV per baris: `ax,ay,az,gx,gy,gz` pada baud rate `115200`, frekuensi tetap
   (contoh 100Hz, sesuai `SAMPLE_RATE_HZ` di `config.h`). Kamu bisa reuse `Mpu6050Sensor` yang sudah
   ada — tinggal `Serial.printf("%.4f,%.4f,%.4f,%.4f,%.4f,%.4f\n", ...)` tiap sample.
3. Jalankan: `edge-impulse-data-forwarder` lalu login, pilih project, dan device akan otomatis
   terhubung. Data akan langsung masuk ke dashboard Edge Impulse "Data acquisition".

### Opsi B — Upload manual file CSV
Kalau forwarder susah setup, kamu bisa capture data ke Serial Monitor, copy-paste ke file `.csv`,
lalu upload manual di tab **Data acquisition > Upload data** di Edge Impulse Studio.

### Berapa banyak data yang dibutuhkan?
- Minimal **~30-50 sample per gesture** (tiap sample = 1 jendela ~1 detik gerakan penuh).
- Pastikan variasi: beberapa dari kamu sendiri melakukan gesture dengan kecepatan/sudut sedikit
  berbeda tiap kali, supaya model tidak overfit ke 1 gaya gerakan saja.
- Tambahkan juga kelas **"idle"/"noise"** — data saat wand didiamkan atau digerakkan random tanpa
  maksud gesture tertentu. Ini penting supaya model tidak salah trigger terus-menerus.
- Split otomatis Edge Impulse: 80% train / 20% test cukup untuk mulai.

Label yang dipakai di firmware ini (harus persis sama, lowercase):
- `lumos`
- `wave`
- `circle`
- (opsional) `idle` / `noise`

## 3. Buat Impulse (pipeline pemrosesan)

1. Tab **Create impulse**:
   - **Window size**: `1000 ms` (harus SAMA dengan `GESTURE_WINDOW_MS` di `config.h`)
   - **Window increase**: `500 ms` (atau sesuai preferensi, untuk augmentasi data)
   - **Frequency**: `100 Hz` (harus SAMA dengan `SAMPLE_RATE_HZ` di `config.h`)
2. Tambah processing block: **Spectral Analysis** (cocok untuk data motion/IMU).
3. Tambah learning block: **Classification (Keras)**.
4. Klik **Save Impulse**.

## 4. Generate features
Buka tab **Spectral features**, klik **Generate features** — Edge Impulse akan proses semua data
training jadi fitur numerik dan tampilkan visualisasi cluster antar kelas (kalau kelas kepisah jelas
di grafik, tandanya gesture cukup berbeda satu sama lain).

## 5. Training
1. Buka tab **Classifier (NN)**.
2. Pakai setting default dulu (epoch ~30-100, learning rate default).
3. Pilih **quantized (int8)** di opsi "select a model" untuk ukuran model paling kecil & cepat di
   ESP32 — penting karena RAM ESP32 terbatas.
4. Klik **Start training**, tunggu selesai, cek **accuracy** dan **confusion matrix**. Target
   accuracy >90% untuk gesture yang jelas berbeda gerakannya.

## 6. Testing
Buka tab **Model testing**, jalankan test terhadap 20% data yang di-hold-out tadi. Kalau akurasi
test jauh lebih rendah dari training accuracy, kemungkinan overfitting — tambah variasi data.

## 7. Deploy ke Arduino library
1. Buka tab **Deployment**.
2. Pilih target **Arduino library**.
3. Centang **EON Compiler** (opsional, biasanya bikin model lebih kecil/cepat).
4. Klik **Build** — akan download file `.zip`.
5. Di Arduino IDE: **Sketch > Include Library > Add .ZIP Library...** lalu pilih file tadi.
6. Buka contoh sketch bawaan (`File > Examples > <nama_project>_inferencing > ...`) untuk lihat
   nama header yang benar, biasanya `<nama_project>_inferencing.h`.

## 8. Integrasi ke firmware repo ini
1. Buka `firmware/magic_wand/gesture_classifier.cpp`, ganti baris:
   ```cpp
   #include <your_project_inferencing.h>
   ```
   dengan nama header asli dari project Edge Impulse kamu.
2. Buka `firmware/magic_wand/gesture_classifier.h`, ubah:
   ```cpp
   #define USE_EDGE_IMPULSE_MODEL 0
   ```
   menjadi:
   ```cpp
   #define USE_EDGE_IMPULSE_MODEL 1
   ```
3. Pastikan urutan label di `classifyEdgeImpulse()` (`lumos`, `wave`, `circle`) sesuai persis dengan
   nama label yang kamu pakai saat training di Edge Impulse Studio.
4. Compile & upload. Cek Serial Monitor — kalau ada error compile terkait memori penuh
   ("region overflowed"), coba kurangi ukuran model (lower epoch/complexity) atau pakai
   `EON Compiler` saat deploy.

## Tips supaya nggak salah
- **Konsistensi window & frequency** antara `config.h` firmware dan setting Edge Impulse itu WAJIB
  sama — kalau beda, klasifikasi akan ngaco walau model "terlihat" berhasil training.
- Jangan lupa test langsung dengan device fisik (bukan cuma di dashboard EI) — noise sensor asli
  kadang beda dengan data yang di-collect lewat forwarder karena timing/jitter software serial.
- Kalau model terlalu besar untuk ESP32 (RAM error saat compile), turunkan kompleksitas Spectral
  Analysis block (kurangi jumlah filter/FFT length) sebelum training ulang.

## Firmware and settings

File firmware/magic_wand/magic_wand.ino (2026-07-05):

// magic_wand.ino — AI Magic Wand firmware utama
//
// Dua cara memicu AI:
//  1. GESTURE (mis. "Wave"): sensor mendeteksi gerakan tertentu, server AI
//     jawab pakai prompt TETAP untuk gesture itu (lihat GESTURE_PROMPTS di
//     server/gesture_server.js).
//  2. PUSH-TO-TALK (tombol BOOT): tahan tombol sambil bicara, lepas untuk
//     kirim rekaman ke server. Server transkrip suara kamu (speech-to-text)
//     dan AI jawab SESUAI ISI OMONGAN kamu, bukan prompt tetap.
// Di kedua cara, jawaban AI (teks + audio) tampil di OLED dan diputar lewat
// speaker I2S di tongkat.
//
// Alur gesture:
//  1. Idle: baca sensor terus-menerus, tunggu percepatan melewati threshold (trigger gesture).
//  2. Saat trigger, tangkap jendela sampel (GESTURE_WINDOW_MS) untuk diklasifikasi.
//  3. Klasifikasi gesture (model Edge Impulse atau fallback threshold, lihat gesture_classifier.h).
//  4. Nyalakan LED sesuai gesture.
//  5. Jika gesture == WAVE (atau gesture lain yang kamu mau), kirim ke AI API dan tampilkan respons.
//  6. Jika idle terlalu lama, masuk deep sleep; bangun otomatis saat ada motion (interrupt MPU6050).
//
// Sebelum upload, siapkan:
//  - Copy secrets.h.example -> secrets.h dan isi WiFi + alamat server AI lokal
//  - Install library: Adafruit MPU6050, Adafruit Unified Sensor, Adafruit SSD1306,
//    Adafruit GFX Library, ArduinoJson, ESP32-audioI2S (by schreibfaul1)
//  - (Opsional) install library hasil export Edge Impulse, lalu set USE_EDGE_IMPULSE_MODEL=1
//    di gesture_classifier.h

#include "config.h"
#include "mpu6050_sensor.h"
#include "gesture_classifier.h"
#include "led_effects.h"
#include "oled_display.h"
#include "ai_client.h"
#include "audio_player.h"
#include "mic_recorder.h"
#include "power_manager.h"

Mpu6050Sensor sensor;
GestureClassifier classifier;
LedEffects leds;
OledDisplay oled;
AiClient ai;
AudioPlayer speaker;
MicRecorder mic;
PowerManager power;

enum class State { IDLE, CAPTURING, CLASSIFYING };
State state = State::IDLE;

uint32_t lastSampleMs = 0;
const uint32_t sampleIntervalMs = 1000 / SAMPLE_RATE_HZ;

// Gesture yang memicu pengiriman ke AI (bisa ditambah/dikurangi sesuai kebutuhan)
bool shouldTriggerAI(Gesture g) {
  return g == Gesture::WAVE;
}

// Dipanggil MicRecorder::record() berulang kali untuk cek kapan berhenti rekam
// (tombol dilepas = active HIGH karena PIN_BUTTON pakai INPUT_PULLUP, active LOW saat ditekan)
bool isButtonReleased() {
  return digitalRead(PIN_BUTTON) == HIGH;
}

// Tampilkan + mainkan balasan AI (dipakai baik dari gesture maupun push-to-talk).
// WiFi HARUS masih nyala saat dipanggil -- baru boleh disconnectWifi() setelah ini selesai.
void playAiReply(const AiReply &reply) {
#if DEBUG_PRINT
  Serial.print("[AI] Respons: ");
  Serial.println(reply.text);
#endif
  oled.showAiResponse(reply.text.c_str());

  if (reply.audioUrl.length() > 0) {
#if DEBUG_PRINT
    Serial.print("[Audio] Streaming: ");
    Serial.println(reply.audioUrl);
#endif
    if (speaker.playUrl(reply.audioUrl)) {
      uint32_t playStart = millis();
      while (speaker.isPlaying() && millis() - playStart < 20000) {
        speaker.loop();
      }
    } else {
#if DEBUG_PRINT
      Serial.println("[Audio] Gagal mulai streaming, lanjut tanpa suara.");
#endif
      delay(3000);
    }
  } else {
    delay(3000);
  }
}

void handlePushToTalk() {
  oled.showMessage("Mendengarkan...", "Lepas tombol utk kirim");
  leds.setColor(0, 200, 200);

  bool gotRecording = mic.record(isButtonReleased);
  leds.off();

  if (!gotRecording) {
#if DEBUG_PRINT
    Serial.println("[Mic] Rekaman terlalu pendek, dibatalkan.");
#endif
    oled.showIdle();
    return;
  }

#if DEBUG_PRINT
  Serial.printf("[Mic] Rekaman selesai, %u bytes\n", (unsigned)mic.wavSize());
#endif
  oled.showMessage("Mengirim ke AI...", "");

  if (!ai.connectWifi()) {
#if DEBUG_PRINT
    Serial.println("[AI] Gagal connect WiFi.");
#endif
    leds.blinkError(2);
    oled.showMessage("WiFi gagal konek", "");
    delay(1500);
    oled.showIdle();
    return;
  }

  AiReply reply;
  if (ai.sendVoice(mic.wavData(), mic.wavSize(), reply)) {
    playAiReply(reply);
  } else {
#if DEBUG_PRINT
    Serial.println("[AI] Gagal mendapat respons suara (cek koneksi/server AI lokal).");
#endif
    leds.blinkError(2);
    oled.showMessage("AI tidak merespons", "Cek server lokal");
    delay(1500);
  }
  ai.disconnectWifi();

  power.notifyActivity();
  oled.showIdle();
}

void setup() {
  Serial.begin(SERIAL_BAUD);
  delay(200);
#if DEBUG_PRINT
  Serial.println("\n=== AI Magic Wand ===");
#endif

  power.logWakeReason();
  power.begin();

  leds.begin();

  pinMode(PIN_BUTTON, INPUT_PULLUP);

  if (!sensor.begin()) {
#if DEBUG_PRINT
    Serial.println("[FATAL] MPU6050 tidak terdeteksi. Cek wiring I2C.");
#endif
    leds.blinkError(10);
    while (true) delay(1000);
  }
  sensor.configureMotionInterrupt();
  classifier.begin();

  if (!oled.begin()) {
#if DEBUG_PRINT
    Serial.println("[Warn] OLED tidak terdeteksi, lanjut tanpa tampilan OLED.");
#endif
  }

  speaker.begin();

  if (!mic.begin()) {
#if DEBUG_PRINT
    Serial.println("[Warn] Mikrofon gagal init, push-to-talk tidak akan jalan.");
#endif
  }

#if DEBUG_PRINT
  Serial.println("[Setup] Selesai. Siap deteksi gesture / tahan tombol BOOT utk bicara.");
#endif
}

void loop() {
  // Push-to-talk: cek dulu sebelum sampling gesture, hanya di state IDLE
  // supaya tidak bentrok dengan proses capture/classify gesture yang sedang jalan.
  if (state == State::IDLE && digitalRead(PIN_BUTTON) == LOW) {
    power.notifyActivity();
    handlePushToTalk();
    lastSampleMs = millis();
    return;
  }

  uint32_t now = millis();
  if (now - lastSampleMs < sampleIntervalMs) {
    // Isi waktu luang dengan efek idle breathing + cek deep sleep, tanpa nge-block sampling
    if (state == State::IDLE) leds.idleBreath();
    return;
  }
  lastSampleMs = now;

  GyroSample sample;
  if (!sensor.read(sample)) {
#if DEBUG_PRINT
    Serial.println("[Warn] Gagal baca sensor");
#endif
    return;
  }

  switch (state) {
    case State::IDLE: {
      float mag = sensor.accelMagnitude(sample);
      if (mag > GESTURE_TRIGGER_THRESHOLD_G) {
        power.notifyActivity();
        classifier.reset();
        classifier.addSample(sample);
        state = State::CAPTURING;
#if DEBUG_PRINT
        Serial.println("[State] Trigger terdeteksi, mulai capture gesture...");
#endif
      } else if (power.shouldSleep()) {
        leds.off();
        oled.showMessage("Tidur...", "Gerakkan utk bangun");
        power.enterDeepSleep(); // tidak return, ESP32 reset setelah bangun
      }
      break;
    }

    case State::CAPTURING: {
      bool full = classifier.addSample(sample);
      if (full) {
        state = State::CLASSIFYING;
      }
      break;
    }

    case State::CLASSIFYING: {
      Gesture g = classifier.classify();
#if DEBUG_PRINT
      Serial.printf("[Gesture] Terdeteksi: %s\n", gestureName(g));
#endif
      leds.playForGesture(g);
      oled.showGesture(gestureName(g));

      if (shouldTriggerAI(g)) {
        oled.showMessage("Menghubungi AI...", "");
        if (ai.connectWifi()) {
          AiReply reply;
          if (ai.sendGesture(gestureName(g), reply)) {
            playAiReply(reply);
          } else {
#if DEBUG_PRINT
            Serial.println("[AI] Gagal mendapat respons (cek koneksi/server AI lokal).");
#endif
            leds.blinkError(2);
            oled.showMessage("AI tidak merespons", "Cek server lokal");
            delay(1500);
          }
          ai.disconnectWifi(); // matikan WiFi lagi untuk hemat daya (setelah audio selesai)
        } else {
#if DEBUG_PRINT
          Serial.println("[AI] Gagal connect WiFi.");
#endif
          leds.blinkError(2);
          oled.showMessage("WiFi gagal konek", "");
          delay(1500);
        }
      }

      classifier.reset();
      power.notifyActivity();
      state = State::IDLE;
      oled.showIdle();
      break;
    }
  }
}

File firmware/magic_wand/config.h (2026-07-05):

// config.h — pengaturan umum proyek AI Magic Wand
// Ubah nilai di sini untuk menyesuaikan hardware/perilaku tanpa menyentuh logika utama.
#pragma once

// ---------- Pin mapping (ESP32 DevKit V1) ----------
#define PIN_I2C_SDA        21
#define PIN_I2C_SCL        22
#define PIN_MPU_INT        27   // pin interrupt MPU6050 (wake-on-motion dari deep sleep)
#define PIN_LED_R          25
#define PIN_LED_G          26
#define PIN_LED_B          33
#define PIN_BUTTON         0    // tombol BOOT bawaan, dipakai untuk push-to-talk (tahan+bicara+lepas)

// LED aktif LOW jika pakai modul RGB common-anode. Set false jika common-cathode.
#define LED_ACTIVE_LOW     false

// ---------- OLED (SSD1306 0.96" I2C) ----------
// Pakai bus I2C yang sama dengan MPU6050 (SDA=21, SCL=22) — SSD1306 alamat default 0x3C,
// MPU6050 alamat default 0x68, jadi tidak bentrok di 1 bus.
#define OLED_ENABLED        true
#define OLED_WIDTH          128
#define OLED_HEIGHT         64
#define OLED_I2C_ADDR       0x3C

// ---------- Speaker (I2S, MAX98357A amp + speaker mini) ----------
// Suara AI di-generate & di-TTS di server (dinamis, beda tiap gesture),
// lalu ESP32 STREAMING file audio itu lewat WiFi dan mainkan langsung via
// I2S -- ESP32 sendiri tidak generate suara apapun.
#define SPEAKER_ENABLED     true
#define PIN_I2S_BCLK        14
#define PIN_I2S_LRC         32
#define PIN_I2S_DOUT        13
#define SPEAKER_VOLUME      12   // skala 0-21 (library ESP32-audioI2S)

// ---------- Mikrofon (I2S, INMP441) + push-to-talk ----------
// Tahan PIN_BUTTON (tombol BOOT) sambil bicara, lepas untuk kirim. Audio
// direkam ke RAM (WAV 16kHz/16-bit mono), dikirim ke server AI lokal untuk
// speech-to-text, lalu server jawab pakai teks hasil transkrip itu -- BUKAN
// lagi prompt tetap per gesture. ESP32 sendiri tidak melakukan STT apapun.
#define MIC_ENABLED         true
#define PIN_MIC_SCK         4     // I2S clock (BCLK) mikrofon
#define PIN_MIC_WS          5     // I2S word select (LRC) mikrofon
#define PIN_MIC_SD          18    // I2S data OUT dari mic ke ESP32
#define MIC_SAMPLE_RATE_HZ  16000 // 16kHz cukup untuk speech-to-text, hemat RAM/bandwidth
#define MIC_MAX_RECORD_MS   3000  // batas rekam maksimal (ms) -- ESP32 tanpa PSRAM RAM-nya
                                  // terbatas, 3 detik @16kHz mono ~= 96KB, cukup aman
#define MIC_MIN_RECORD_MS   400   // rekaman lebih pendek dari ini dianggap tidak sengaja/noise

// ---------- Sampling gesture ----------
#define SAMPLE_RATE_HZ         100     // frekuensi sampling accel/gyro
#define GESTURE_WINDOW_MS      1000    // panjang jendela sampel per gesture (harus sama dgn training Edge Impulse)
#define GESTURE_TRIGGER_THRESHOLD_G   1.5f // percepatan (dalam g) yang memicu mulai menangkap gesture

// ---------- Deep sleep / power ----------
#define IDLE_TIMEOUT_MS         30000  // masuk deep sleep jika tak ada gerakan selama ini (ms)
#define DEEP_SLEEP_ENABLED      true

// ---------- WiFi & AI lokal ----------
// Isi kredensial asli di secrets.h (jangan commit secrets.h ke git publik)
#include "secrets.h"

// AI lokal (speech-to-speech / speech-to-text) diakses lewat HTTP POST JSON di jaringan lokal.
// Alamat server diisi di secrets.h lewat LOCAL_AI_HOST — boleh hostname mDNS ("namaserver.local")
// ATAU IP statis ("192.168.1.50"), dua-duanya jalan tanpa ubah kode di sini.
#define LOCAL_AI_PORT       5000          // sesuaikan dengan port server AI lokal kamu
#define LOCAL_AI_PATH       "/gesture"    // sesuaikan dengan endpoint API server AI lokal kamu
#define LOCAL_AI_USE_HTTPS  false         // AI lokal biasanya HTTP biasa (tanpa TLS) di LAN

// ---------- Debug ----------
#define SERIAL_BAUD      115200
#define DEBUG_PRINT      true

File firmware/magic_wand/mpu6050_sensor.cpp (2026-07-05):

// mpu6050_sensor.cpp
// Menggunakan library "Adafruit MPU6050" + "Adafruit Unified Sensor" (install lewat Library Manager).
#include "mpu6050_sensor.h"
#include "config.h"
#include <Wire.h>
#include <Adafruit_MPU6050.h>
#include <Adafruit_Sensor.h>

static Adafruit_MPU6050 mpu;

bool Mpu6050Sensor::begin() {
  Wire.begin(PIN_I2C_SDA, PIN_I2C_SCL);
  if (!mpu.begin()) {
    return false;
  }
  mpu.setAccelerometerRange(MPU6050_RANGE_4_G);
  mpu.setGyroRange(MPU6050_RANGE_500_DEG);
  mpu.setFilterBandwidth(MPU6050_BAND_44_HZ);
  return true;
}

bool Mpu6050Sensor::read(GyroSample &out) {
  sensors_event_t a, g, temp;
  if (!mpu.getEvent(&a, &g, &temp)) {
    return false;
  }
  // Adafruit lib mengembalikan accel dalam m/s^2 dan gyro dalam rad/s; konversi ke g dan deg/s
  const float G = 9.80665f;
  out.ax = a.acceleration.x / G;
  out.ay = a.acceleration.y / G;
  out.az = a.acceleration.z / G;
  out.gx = g.gyro.x * 180.0f / PI;
  out.gy = g.gyro.y * 180.0f / PI;
  out.gz = g.gyro.z * 180.0f / PI;
  return true;
}

float Mpu6050Sensor::accelMagnitude(const GyroSample &s) const {
  return sqrtf(s.ax * s.ax + s.ay * s.ay + s.az * s.az);
}

void Mpu6050Sensor::configureMotionInterrupt(uint8_t threshold, uint8_t duration) {
  // Adafruit_MPU6050 tidak expose register motion-detection langsung, jadi tulis manual via I2C.
  // Register MPU6050: 0x1F=MOT_THR, 0x20=MOT_DUR, 0x37=INT_PIN_CFG, 0x38=INT_ENABLE
  const uint8_t MPU_ADDR = 0x68;

  auto writeReg = [&](uint8_t reg, uint8_t val) {
    Wire.beginTransmission(MPU_ADDR);
    Wire.write(reg);
    Wire.write(val);
    Wire.endTransmission();
  };

  writeReg(0x1F, threshold);      // MOT_THR
  writeReg(0x20, duration);       // MOT_DUR
  writeReg(0x37, 0x20);           // INT_PIN_CFG: latch, active high, push-pull
  writeReg(0x38, 0x40);           // INT_ENABLE: motion detection interrupt
}

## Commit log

2026-07-05 Add AI Magic Wand firmware, docs, and BOM for ESP32 + MPU6050
    Initial project scaffold: gesture-triggered ESP32 firmware (MPU6050 sensing,
    on-device threshold classifier with Edge Impulse model hook, RGB LED feedback,
    WiFi + OpenAI/Grok text response, deep sleep with motion wake), plus BOM,
    wiring guide, Edge Impulse training guide, and enclosure suggestions.
2026-07-05 Add OLED display and switch AI backend to local speech AI server
    Replace cloud OpenAI/Grok integration with a local network AI server
    (speech-to-speech/speech-to-text) reached via HTTP JSON, resolved by
    mDNS hostname or static IP. Add SSD1306 0.96" I2C OLED for showing the
    detected gesture name and the AI's text response, sharing the I2C bus
    with the MPU6050. Update docs accordingly.
    [ai_client.cpp, config.h, magic_wand.ino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]
2026-07-05 Add local gesture AI server implementing ESP32's expected /gesture contract
    Adapts the AI4Chat client and TTS logic from Faganlenwy's whisper-server.js
    into a standalone server/ that speaks the required protocol: POST /gesture
    {gesture} -> JSON {text} for the OLED, with speech-to-speech handled locally
    via speaker playback instead of sending audio back to the ESP32.
2026-07-05 Add 3D-printable wand handle design (OpenSCAD source + STL exports)
    Parametric tapered handle with decorative rings, M2 self-tapping screw
    bosses aligned to the rings, USB/switch/OLED cutouts, and a matching
    front shaft with LED tip mount. Includes render previews.
    [magic_wand_grip_bottom.stl, magic_wand_grip_top.stl, magic_wand_handle.scad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]
2026-07-05 Add assembled-view OpenSCAD preview for the wand handle
    Shows grip_bottom + grip_top unioned into one closed tube with the
    front shaft attached, so the joined result can be inspected directly
    instead of the three parts side by side.
    [magic_wand_assembled_preview.scad]
2026-07-05 Fix screw boss placement to actually sit on the shell seam
    Previous tabs were placed at diametrically opposite points of the
    tube (bottom of the circle for the lower shell, top for the upper
    shell), so no single screw could ever pass through both halves.
    Bosses now straddle the flat parting line, so bottom and top each
    contribute half of one continuous boss with a hole running straight
    through when assembled.
    [magic_wand_assembled_preview.scad, magic_wand_grip_bottom.stl, magic_wand_grip_top.stl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]
2026-07-05 Add countersink for flush screw heads
    No printed threads — self-tapping screws already handle grip via the
    undersized pilot hole, and printed M2-scale threads are unreliable on
    consumer FDM printers. Countersink just lets the screw head sit flush
    at the flange's outer face.
    [magic_wand_assembled_preview.scad, magic_wand_grip_bottom.stl, magic_wand_grip_top.stl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]
2026-07-05 Remove duplicate OLED cutout from bottom shell
    The OLED only faces one direction, so cutting its window into both
    shells left a pointless hole on the side facing the back of the
    module. The window now only exists in grip_top, where the display
    actually faces.
    [magic_wand_assembled_preview.scad, magic_wand_grip_bottom.stl, magic_wand_grip_top.stl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]
2026-07-05 Add on-wand speaker output via I2S audio streaming
    The wand now speaks its own AI responses instead of the server playing
    them locally. The server generates TTS audio, serves it as a static
    mp3 (auto-deleted after 60s), and returns its URL alongside the OLED
    text. The ESP32 streams and plays that URL over I2S (MAX98357A amp +
    speaker) using ESP32-audioI2S, keeping WiFi up until playback finishes.
    Also updates BOM/wiring docs for the new amp/speaker and I2S pins
    (GPIO14/32/13, chosen to avoid conflicts with existing I2C/LED/MPU
    interrupt pins).
    [ai_client.cpp, config.h, magic_wand.ino]
2026-07-05 Add voice input (push-to-talk) with local speech-to-text
    The wand can now be talked to, not just gestured at. Hold the BOOT
    button to record, release to send -- ESP32 captures 16kHz mono WAV via
    I2S mic (INMP441) into RAM and POSTs it to a new /voice endpoint. The
    server transcribes it locally with Whisper (Xenova/transformers,
    offline after the one-time model download) and feeds the transcript
    into the same ask-AI-then-TTS pipeline gestures already use, so the
    wand answers what you actually said instead of a fixed per-gesture
    prompt.
    Refactored ai_client.cpp to share host resolution and reply parsing
    between sendGesture() and the new sendVoice(). Refactored
    gesture_server.js's ask+speak lo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
    [magic_wand_assembled_preview.scad, magic_wand_grip_bottom.stl, magic_wand_grip_top.stl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]
